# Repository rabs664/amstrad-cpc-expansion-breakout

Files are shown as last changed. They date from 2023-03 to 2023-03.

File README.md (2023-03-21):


# amstrad-cpc-expansion-breakout
Simple PCB with labels and header pins for the Amstrad CPC Expansion Bus, compatible with an MX4 connector.

Allows Amstrad CPC Expansion bus signals to be monitored using the labels without having to remember the pin position on the connector.

Source contains Eagle schematic, board and cam output (gerber) files.

Note there is no ESD protection and the headers connect directly to the expansion bus, so care should be taken at all times to prevent accidents.

see Wiki for more info.

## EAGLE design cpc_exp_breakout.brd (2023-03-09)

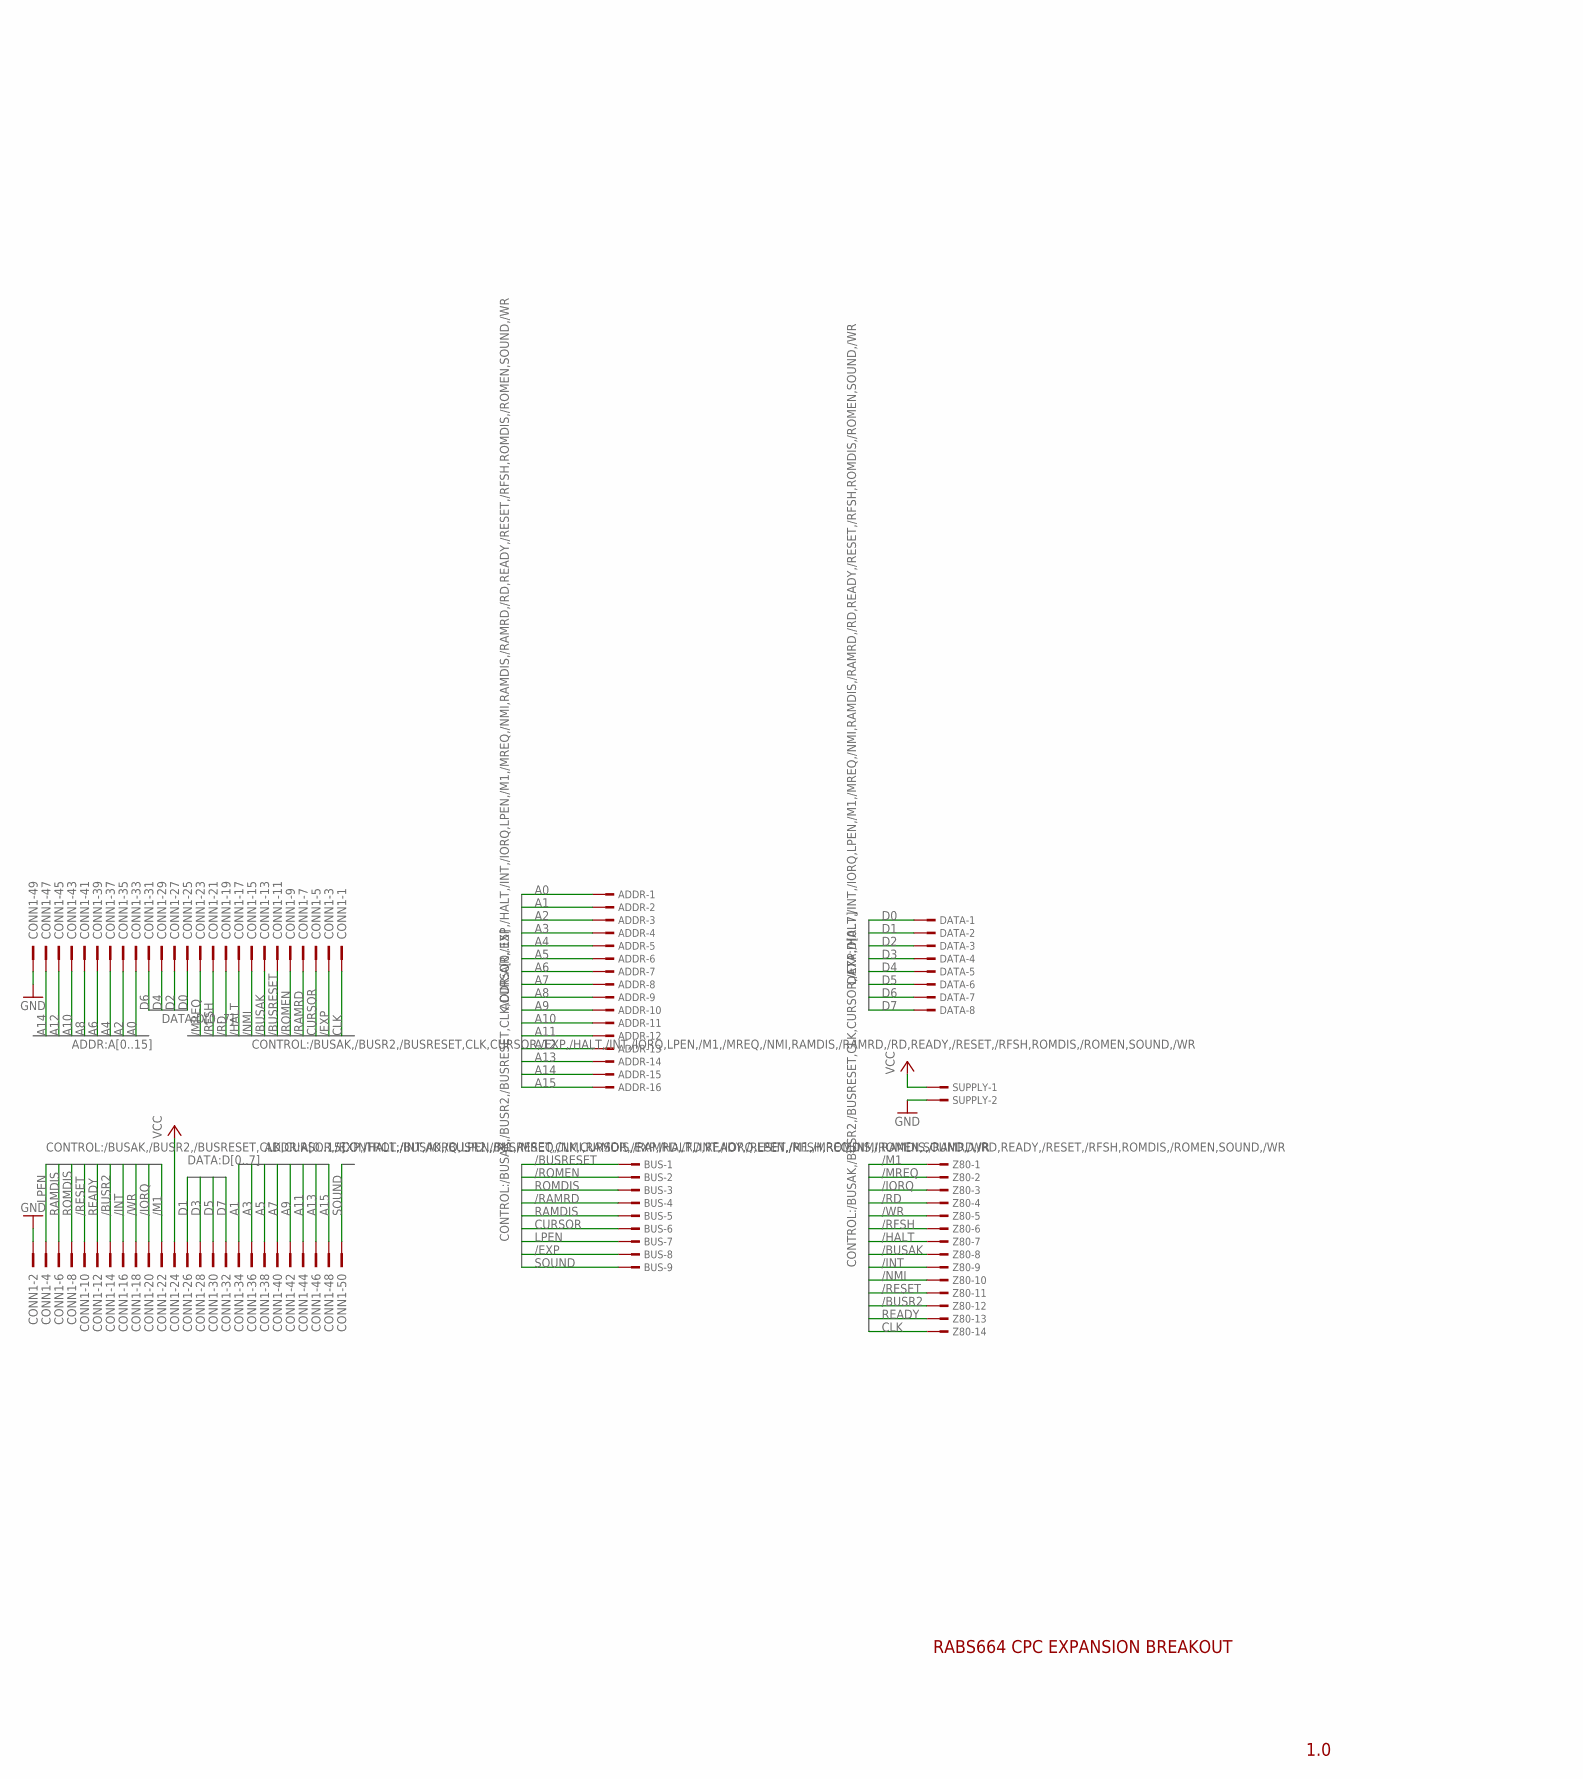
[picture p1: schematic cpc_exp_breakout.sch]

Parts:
ADDR: TSW-116-07-G-S; TSW-116-XX-G-S
BUS: TSW-109-07-G-S; TSW-109-XX-G-S
CONN1: 2550-; PAK100/2500-50
DATA: TSW-108-07-G-S; TSW-108-XX-G-S
SUPPLY: TSW-102-07-G-S; TSW-102-XX-G-S
Z80: TSW-114-07-G-S; TSW-114-XX-G-S

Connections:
/BUSAK: CONN1.13, Z80.8
/BUSR2: CONN1.14, Z80.12
/BUSRESET: BUS.1, CONN1.11
/EXP: BUS.8, CONN1.3
/HALT: CONN1.17, Z80.7
/INT: CONN1.16, Z80.9
/IORQ: CONN1.20, Z80.3
/M1: CONN1.22, Z80.1
/MREQ: CONN1.23, Z80.2
/NMI: CONN1.15, Z80.10
/RAMRD: BUS.4, CONN1.7
/RD: CONN1.19, Z80.4
/RESET: CONN1.10, Z80.11
/RFSH: CONN1.21, Z80.6
/ROMEN: BUS.2, CONN1.9
/WR: CONN1.18, Z80.5
A0: ADDR.1, CONN1.33
A1: ADDR.2, CONN1.34
A2: ADDR.3, CONN1.35
A3: ADDR.4, CONN1.36
A4: ADDR.5, CONN1.37
A5: ADDR.6, CONN1.38
A6: ADDR.7, CONN1.39
A7: ADDR.8, CONN1.40
A8: ADDR.9, CONN1.41
A9: ADDR.10, CONN1.42
A10: ADDR.11, CONN1.43
A11: ADDR.12, CONN1.44
A12: ADDR.13, CONN1.45
A13: ADDR.14, CONN1.46
A14: ADDR.15, CONN1.47
A15: ADDR.16, CONN1.48
CLK: CONN1.1, Z80.14
CURSOR: BUS.6, CONN1.5
D0: CONN1.25, DATA.1
D1: CONN1.26, DATA.2
D2: CONN1.27, DATA.3
D3: CONN1.28, DATA.4
D4: CONN1.29, DATA.5
D5: CONN1.30, DATA.6
D6: CONN1.31, DATA.7
D7: CONN1.32, DATA.8
GND: CONN1.2, CONN1.49, SUPPLY.2
LPEN: BUS.7, CONN1.4
RAMDIS: BUS.5, CONN1.6
READY: CONN1.12, Z80.13
ROMDIS: BUS.3, CONN1.8
SOUND: BUS.9, CONN1.50
VCC: CONN1.24, SUPPLY.1

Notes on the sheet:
1.0
RABS664 CPC EXPANSION BREAKOUT

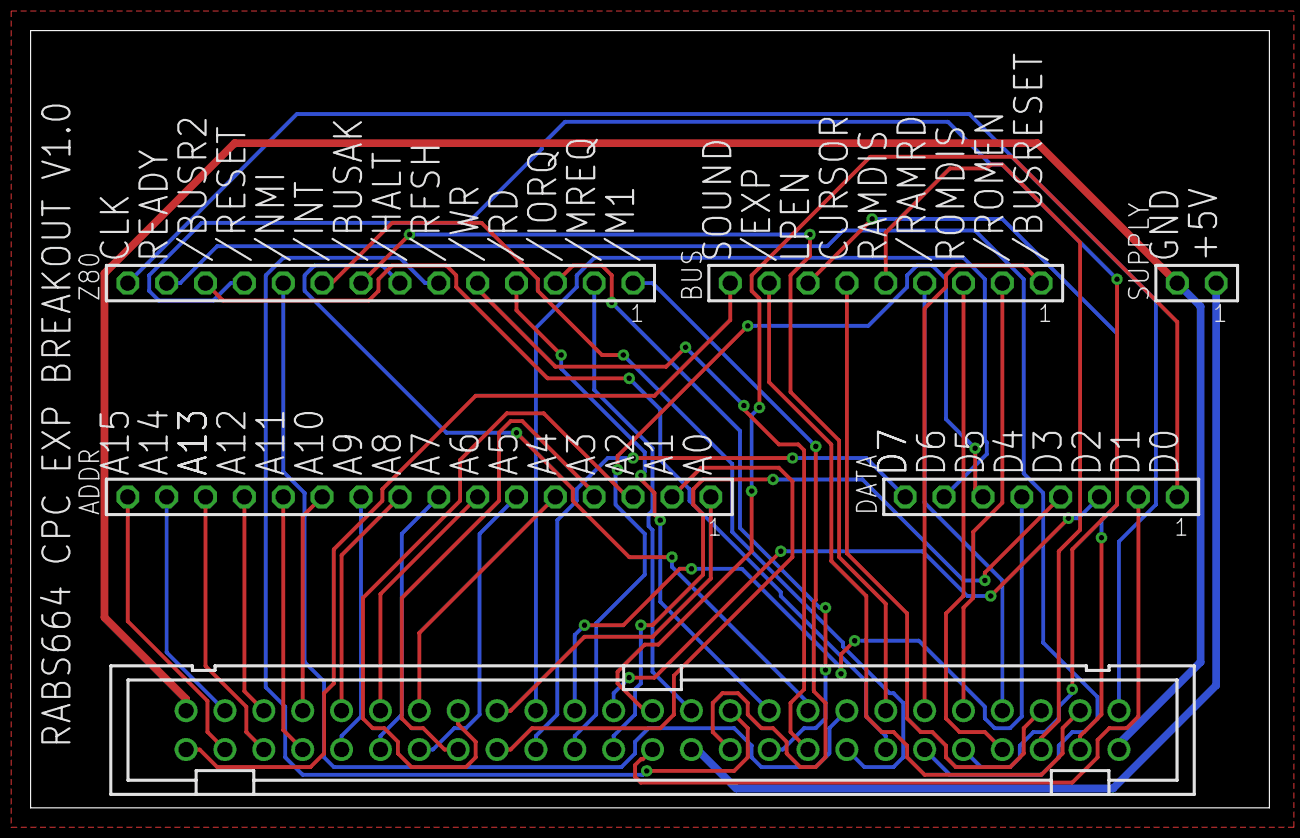
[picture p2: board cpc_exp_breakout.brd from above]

Board: 2 copper layers, 81.0 x 50.8 mm, 6 parts (0 on the bottom side), 49 nets.

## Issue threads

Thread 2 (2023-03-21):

Use socket headers rather than posts

rabs664, 2023-03-21:
With header posts there is always a danger that two posts may be shorted together accidentally. Change to use socket headers rather than posts.

rabs664, 2023-03-25:
Schematic does not need to change to accommodate socket headers rather than posts but Digi-Key list updated and Wiki image changed to match.

Closed 2023-03-25.
